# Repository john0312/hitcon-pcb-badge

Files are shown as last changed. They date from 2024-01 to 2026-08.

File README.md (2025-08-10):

# HITCON PCB Badge

## Firmware Development

execute `fw/merge.py` to merge STM32CubeIDE generated `main.c` with user code in `main.cc` into `main.cc`.

### Choose your hardware

In STM32CubeIDE, go to **Project > Build Configurations > Set Active > V1.1 / V2.0 / V2.1** to switch between hardware versions.  
Then go to **Run > Run Configurations** choose the correct Run Configuration
There are different firmware versions for each hardware revision.  
To identify your hardware version, check the back of your badge.
- V1.1 (2024 CMT Attendee)
- V2.0 (2025 first prototype)
- V2.1 (2025 last prototype)
- V2.2 (2025 Attendee)

## Timers and DMA Channels

- [x] IR Tx: PWM Output from TIM3_CH3, Output PB0, DMA1 Ch2
  - Compare: 63/4 = 16
  - Mode: Circular Normal Peripheral to Memory

| | Peripheral | Memory |
| --- | --- | --- |
| Increment Address | X | V |
| Data Width | Half Word  | Half Word |

- [x] IR Rx: DMA Triggered through TIM2_CH3, Input PA0 read by DMA1 Ch1
  - Compare: 105
  - Mode: Circular Peripheral to Memory

| | Peripheral | Memory |
| --- | --- | --- |
| Increment Address | X | V |
| Data Width | Half Word  | Half Word |

- [x] Led Rows/Cols: DMA Triggered through TIM1_UP, Output PB6-9(Rows), Output PB1-2/10-15(Cols), written by DMA1 Ch5
  - Mode: Circular Memory to Peripheral

| | Peripheral | Memory |
| --- | --- | --- |
| Increment Address | X | V |
| Data Width | Word | Word |

- [x] Led Brightness control: PWM Output from TIM3_CH2
- [x] Buttons: Reads Input PA4-10, PA15 through TIM4_CH2, DMA1 Ch4
  - Compare: 5
  - Mode: Circular Peripheral to Memory

| | Peripheral | Memory |
| --- | --- | --- |
| Increment Address | X | V |
| Data Width | Half Word  | Half Word |

- [x] Cross-board communication TX: USART2 TX, DMA1 Ch7
- [x] Cross-board communication RX: USART2 RX, DMA1 Ch6

- [x] TIM4: Operates at 100Hz for Button
  - Prescaler: 12000-1
  - Counter Period: 10-1
- [x] TIM3: Operates at 38kHz for PWM out.
  - Prescaler: 5-1
  - Counter Period: 63-1
  - Master Mode Enable
- [x] TIM2:
  - Prescaler: 0
  - Counter Period: 4-1
  - Slave Mode: External Clock
  - Trigger Source: ITR2 (TIM3 Update Event)
  - Operates at 1/4 speed of TIM3, synchronization needed for IR pulse alignment and brightness adjustment.
  - Also operates at 1/4 bit time for capturing IR.
  - TIM2 = 38/4 kHz = 9.5kHz.
  - Bit time = 4/9.5kHz = 421us (each bit is 16 pulse).
- [x] TIM1:
  - Prescaler: 5-1
  - Counter Period: 1500-1
  - LED refreshes at 3200/16 = 200Hz.

## Format

To check format, please install `clang-format` first.

```sh
# under hitcon-pcb-badge
./lint.sh # check format
./lint.sh -i # auto format
```

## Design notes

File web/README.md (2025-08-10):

# pcb-badge-leaderboard

## Development server

To start a local development server, run:

```bash
ng serve
```

## Building

To build the project run:

```bash
ng build
```

This will compile your project and store the build artifacts in the `dist/` directory. By default, the production build optimizes your application for performance and speed.

## Running unit tests

To execute unit tests with the [Karma](https://karma-runner.github.io) test runner, use the following command:

```bash
ng test
```

## Running end-to-end tests

For end-to-end (e2e) testing, run:

```bash
ng e2e
```

Angular CLI does not come with an end-to-end testing framework by default. You can choose one that suits your needs.

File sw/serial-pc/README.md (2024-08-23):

# Serial-PC

To verify the score on PCB badge, connect badge to PC by serial and run the command:

```
cargo run -- --dump

# help
cargo run -- --help
```

To connect to a specific serial device, use `--dev` command line argument.

To install `cargo` and relevant rust tools, follow the [Rust website](https://www.rust-lang.org/tools/install).

## Hardware Setup

badge-serial

## client

If you run `cargo run` twice, the second instance will become client mode, and you can send data to the badge.

```
cargo run -- --send-game-data --col 0 --data-int 1

# help
cargo run -- --help
```

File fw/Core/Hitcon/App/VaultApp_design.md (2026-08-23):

# VaultApp — design, invariants, and intended exploit

Internal author notes for the Vault heap-exploitation challenge. This is kept
out of the source comments on purpose: reading the code and solving the
challenge are separate concerns, and the comments should not spoil the solve.

## Overview

Vault-themed heap-exploitation CTF app. The player's badge (client) remote-
controls the server badge over the xboard connector by forwarding every button
press; the server runs the whole game and drives its own display. All logic
ships in every badge so a player can reverse their own board, but the real flag
exists only in the server build.

## Roles & startup

- Single `VaultApp`; the role is chosen at runtime by the non-const global
  `g_vault_role` (default `Client`). The server build flips the initial value to
  `Server` (`BADGE_ROLE == 0x10` defines `VAULT_SERVER`). Both role code paths
  stay in every binary, so the app is fully reverse-engineerable.
- On xboard peer connect the server enters the vault and re-sends `VAULT_HELLO`
  periodically (a `PeriodicTask` enabled in `OnEntry`, disabled in `OnExit`); a
  client switches into the vault on any hello. The periodic resend recovers the
  case where the client missed the first hello and would otherwise sit on
  `connect_menu`; `OnHelloPacket` is idempotent (already in the vault → no-op).
  Two clients connecting (both `Client`) send no hello and stay on the normal
  `connect_menu` — zero interference.

## Memory model (private pool, lives only in VaultApp.cc)

- `kSlots = 8` fixed-size slots; `kSlotSize = NAME_LEN + 2 = 24`.
- `union Slot { Profile; Key; Locked; Plain; }` — every member begins with a
  1-byte `id` at offset 0, so the "id" byte overlaps across all interpretations.
  - `Profile { u8 id; char name[23]; }` — `name` occupies offsets 1..23. `id` is
    a fixed header (see invariant 3).
  - `Key { u8 id; char desc[22]; u8 used; }` — `id` = the `Locked` id this key
    opens; `used` is the **last** slot byte (offset 23).
  - `Locked { u8 id; char content[23]; }` — the (fake/real) flag.
  - `Plain  { u8 id; char content[23]; }` — decrypted copy shown to the player.
- Allocator: LIFO free-list `free_stack_`; `Alloc` pops, `Free` pushes. This
  metadata is stored separately from `pool_`, so a leak that reads slot bytes
  never trips over allocator bookkeeping.
- The app-side object type is carried on `Ref { Type; Slot* }`, never stored in
  the slot. A leak therefore reads pure object bytes, and a `Ref` can end up
  describing a slot as a type it no longer holds.

## Load-bearing invariants — do NOT "clean these up", they ARE the challenge

1. `Free()` never scrubs the slot bytes and no code re-validates a pointer's
   liveness. Freed data lingers and dangling pointers stay usable → UAF.
2. `Discard()` frees the slot but intentionally does **not** touch `pinned_`.
   If the pin referenced that slot it now dangles. This single dangling-pin
   lifetime bug is the entire vulnerability.
3. `OnNamePacket` sets `profile.id = 0xFF`, outside the item id range
   `0..kNumItems-1`. A stale key that reinterprets a `Profile` slot then reads a
   non-item id, matches no `Locked`, and `Use()` performs only its stray write —
   it never enters the unlock branch. Because `name` starts at offset 1, the
   uploaded text cannot alias `id`, so the player cannot steer which item a stale
   key would unlock. Dropping this or using an item id reintroduces an
   unintended solve (and, worse, the unlock branch would free the profile slot
   and clear the pin, corrupting pool state).
4. `Key.used` is the last slot byte (offset 23). A full 22-char uploaded name
   lands its NUL terminator on that same byte, so the stray write `used = 1`
   overwrites the NUL and the printed name over-reads into the next slot.
5. `ResetGame` reverse-fills the free-list so the three `Locked`s seed into
   `pool[0]`, `pool[1]`, `pool[2]` as id 0, 1, 2. The id-2 `Locked` (the real
   flag) is therefore adjacent to the slot the exploit reuses (pool[1]), which
   is what the over-read lands in.
6. In the legitimate unlock path, `Use()` frees the matched `Locked` **last** so
   that slot tops the free-list and is the next `Alloc()` — this is what makes
   the "unlock frees a slot, next buy/upload reuses it" chain deterministic.
7. Keys are single-purchase (`bought_[]`); the id-2 key costs 999.

## Intended exploit (runs on the server, driven by forwarded buttons)

Start: money 100; key prices `{30, 30, 999}`. The id-2 `Locked` @ pool[2] holds
the real flag; its key costs 999 (unaffordable).

1. **Store → Buy key(id1)** (30): allocates a `Key{id 1}` into inventory.
2. **Inventory → Use key(id1)**: unlocks the id-1 `Locked` @ pool[1]. This
   allocates a new `Plain` slot, copies the decrypted id-1 content into it, and
   adds it to inventory; then it frees the key's slot and the id-1 `Locked`.
   The `Locked` is freed **last**, so pool[1] ends up on top of the free-list.
3. **Store → Buy key(id0)** (30): the allocation reuses pool[1] as a `Key{id 0}`.
4. **Inventory → Pin key(id0)**: sets `pinned_ = {Key, pool[1]}`.
5. **Inventory → Discard key(id0)**: frees pool[1] and removes it from
   inventory; `pinned_` is left untouched, so it now dangles at pool[1].
6. **Main → Name Upload** with a **22-char** name: the allocation reuses pool[1]
   as a `Profile` (`id = 0xFF`, `name` fills offsets 1..22, NUL at offset 23).
7. **Main → Pinned → Use**: the type check passes (the `Ref` still records
   `Key`); `k->used = 1` writes offset 23, clobbering the name's NUL; `t =
   profile.id = 0xFF` matches no `Locked`, so nothing is unlocked — only the
   write happens.
8. **Main → Print**: `view_str_ = profile.name` (offset 1). With the NUL at
   offset 23 gone, `strlen` runs past pool[1] into pool[2] = `Locked{id 2, real
   flag}`. The display pages show: `<22 name chars>` + `0x01` (used) + `0x02`
   (id 2) + the real flag, stopping at the flag's NUL.

Why each piece is needed:

- The **pin** is mandatory: after discard the key is only reachable through
  `pinned_`, so the stale `Use` can only come from the Pinned shortcut.
- The two non-zero bytes between the name and the flag (`used`, then the id) keep
  `strlen` from stopping early.
- Pool contiguity (stride `kSlotSize = 24`) makes the over-read land exactly on
  the adjacent item slot.

## Why it can't be shortcut

- The id-2 key costs 999 → the id-2 `Locked` can't be unlocked legitimately.
- `profile.id = 0xFF` + `name` at offset 1 → the uploaded text can neither alias
  the id nor steer a stale key to unlock an item.
- `Use()`'s unlock branch fires at most once per key: the `used` guard blocks
  re-entry, and on firing the key is removed from inventory + freed and the pin
  is cleared, so there is no live handle to invoke it again.

## Build / deploy

- **Server**: build the station badge with `BADGE_ROLE 0x10` (defines
  `VAULT_SERVER`); fill the real `kFlag0/1/2` in that branch (len
  `<= kSlotSize - 2`). Flash that one badge.
- **Everything else** ships as `Client` with dummy flags, so reversing a
  player's own badge reveals no real challenge content.

## xboard protocol

- Recv ids added before `MAX` in `Logic/XBoardRecvFn.h`: `VAULT_HELLO_ID`,
  `VAULT_BTN_FWD_ID`, `VAULT_NAME_REQ_ID`, `VAULT_NAME_RESP_ID`.
- Packets (`VaultCommon.h`): `VaultBtnPacket { u16 button; }`,
  `VaultNamePacket { char name[kVaultNameBufLen]; }` (`kVaultNameBufLen =
  NAME_LEN + 1 = 23`). Hello and name-req carry a single ignored marker byte.
- The wire buffer size (`kVaultNameBufLen`) is deliberately independent of the
  pool slot size (`kSlotSize`).

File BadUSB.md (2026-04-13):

# BadUSB

(in hex)

```python
device.write(arr)
```

The first byte of `arr` is the Report ID (value 2).  
If `len(arr) > 9`, every 10th, 20th, etc., byte is also a Report ID (2) and will be ignored.  
This means that for the first nine elements of `arr`, there are eight data bytes. Starting from the 10th byte, each segment consists of one Report ID followed by nine data bytes.
**The simplest approach is to always use an array of size 9, as the firmware is designed to handle this format.**
These results were tested on macOS; behavior on Linux may differ slightly but is generally the same.

- 01 XX XX XX XX XX… Set Name
- 02 Clear BadUSB Script
- 03 XX XX Start writing script + script length + CRC32 + ...

  - FF XX delay(20ms per unit)
  - FE XX Modifier
  - FD finish script
  - other: keycode
- 04 XX XX XX XX YY YY YY YY ZZ
  - XX write address
  - YY content
  - ZZ type, bytes, half word, or word

- 05 XX XX XX XX ZZ
  - XX read address
  - ZZ type, bytes, half word, or word

USB return

FF action done

[USB HID Keyboard scan codes](https://gist.github.com/MightyPork/6da26e382a7ad91b5496ee55fdc73db2)

## Windows 開發紀錄

BadUSB 的攻擊腳本是透過 HID 寫入 badge，在 mac 和 linux 上都可以寫入 hidraw，但 windows 上無法寫入。根據搜尋到的資料推測是 windows 不接受對一般鍵盤的 hid 界面寫入任意格式的資料，而 badge 已經模擬成鍵盤因此無法寫入。解決辦法是新增獨立的 usb interface，其中一個是鍵盤，另一個是自訂 hid，這樣 windows 就不會阻止對自訂 hid 的寫入操作了。

USB 裝置描述大致如下

Device Descriptor -> Configuration Descriptor -> Report Descriptor

### Device descriptor

宣告 vendor id (VID), product id (PID)

### Configuration Descriptor

這裡其實包含很多種 descriptor

- Configuration Descriptor * 1
  - Interface Descriptor * n
    - Class-Specific Descriptor: 根據 bInterfaceClass 緊接在後
    - Endpoint Descriptor * m

就是在這裡增加 interface 數量。修改時須參考 USB HID spec

### Report Descriptor

- Collection
  - Report * n

一個 interface 對應到一個 report descriptor，每個 report descriptor 中可能包含多個功能相近的 report，input (to PC) 和 output (from PC) 也是分開的 report。以鍵盤為例，input 是按鍵觸發事件，output 可以是 caps lock 亮燈。

### Debug 工具

```sh
sudo dmesg -w
```

顯示目前插入的 usb 裝置狀況

```sh
hexdump -C /sys/bus/usb/devices/3-1/3-1:1.0/0003:0483:5750.0007/report_descriptor
```

顯示 report descriptor，可丟 copilot 分析

```sh
sudo lsusb -v -d 0483:5750
```

顯示經過解析的 device descriptor, configuration descriptor 等

wireshark: 可以抓 usb 溝通過程

### References

- [使用STM32 H7实现HID组合设备（键盘、鼠标） - 来自Madliar](https://www.madliar.com/notebook/publish/i/caoliang.net/2023-08-27/-shi-yong-STM32H7-shi-xian-HID-zu-he-she-bei--jian-pan--shu-biao-.html)
- [Device Class Definition for Human Interface Devices (HID) version 1.11.pdf](https://www.usb.org/sites/default/files/documents/hid1_11.pdf)
- [Defined Class Codes | USB-IF](https://www.usb.org/defined-class-codes)
- [CaptureSetup/USB - Wireshark Wiki](https://wiki.wireshark.org/CaptureSetup/USB)
- [USB Component: Interface Descriptor](https://www.keil.com/pack/doc/mw/usb/html/_u_s_b__interface__descriptor.html)
- [【经验分享】基于STM32使用HAL库实现USB组合设备之多路CDC - STM32团队 ST意法半导体中文论坛](https://shequ.stmicroelectronics.cn/thread-634270-1-1.html)

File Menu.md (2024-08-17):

```mermaid
flowchart TD
    A[Entry Point] --> B(ShowNameApp)
    B -----> |"Mode\n(single player)"| main_menu_app(MainMenuApp)

    subgraph single_player
        main_menu_app --> D(BadUSB)
        main_menu_app --> E(Snake)
        main_menu_app --> F(Dino)
        main_menu_app --> G(Tetris)
    end

    D --> main_menu_app
    E --> show_score_app
    F --> show_score_app
    G --> show_score_app
    show_score_app(ShowScoreApp) --> |"Button\n(single player)"| main_menu_app

    B -----> |"Mode\n(two player)"| connect_menu_app(ConnectMenuApp)
    subgraph two_player
        connect_menu_app --> O(Tetris)
        connect_menu_app --> P(Snake)
        connect_menu_app --> Q(xchg)
    end

    O --> show_score_app
    P --> show_score_app
    Q --> show_score_app
    show_score_app --> |"Button\n(two player)"| connect_menu_app

    B ------> |Mode Long Pulse| H(NameSettingApp)
    subgraph settings
        H --> I(EditNameApp)
        H --> J(NameDisplayApp)
        J --> K(Name + Score)
        J --> L(Name Only)
        J --> M(Score Only)
    end
```

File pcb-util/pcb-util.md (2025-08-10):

# pcb-util

pcb-util provides an utility tool for flashing FW to PCBs more effiecient in production.

# CLI Tool User Instruction
## Preparation
### Install STM32ProgrammerCLI.exe
1. Log in to MyST on STM32 website
2. Download STM32CubeProgrammer from the [link](https://www.st.com/en/development-tools/stm32cubeprog.html)
3. Unzip the en.stm32cubeprg-win32-v2-17-0.zip
4. Install the SW by double-click SetupSTM32CubeProgrammer_win32 with default configuration
5. Copy the path to STM32_Programmer_CLI. It should be something like this:
  ```
  C:\Program Files (x86)\STMicroelectronics\STM32Cube\STM32CubeProgrammer\bin\STM32_Programmer_CLI.exe
  ```

### Prepare files to flash
1. Download pcb-util_CLI.zip from Github repo.
2. Extract the folder

Here are the files that should be in pcb-util to start flashing with CLI tool

.\pcb-util_CLI
1. fw.elf
2. config.ini
3. pcb-util_CLI.exe

### Set Path to STM32ProgrammerCLI.exe
1. Put the path to ```fw.elf``` into ```[Path] FW_ELF_PATH``` in  ```config.ini``` 
2. Put the path into ```[Path] ST_PPROGRAMMER_PATH``` in  ```config.ini``` 

### Check pcb-log Server
Please check the pcb-log server is ready.

If not, disable this function by changing ```EN_PCB_LOG = 1``` in ```config.ini```

## Use pcb-util_CLI tool
1. Run:
    ```
    python pcb-util_CLI.py
    ```
2. The CLI tool will automatically detect the pcb-badge connected and flash the fwMOD.elf. Remove the pcb-badge once upload was finished
3. If you add/remove ST-Link connected to the PC, press r'to refresh the list of ST-Link 
4. press 'q' to quit the CLI tool

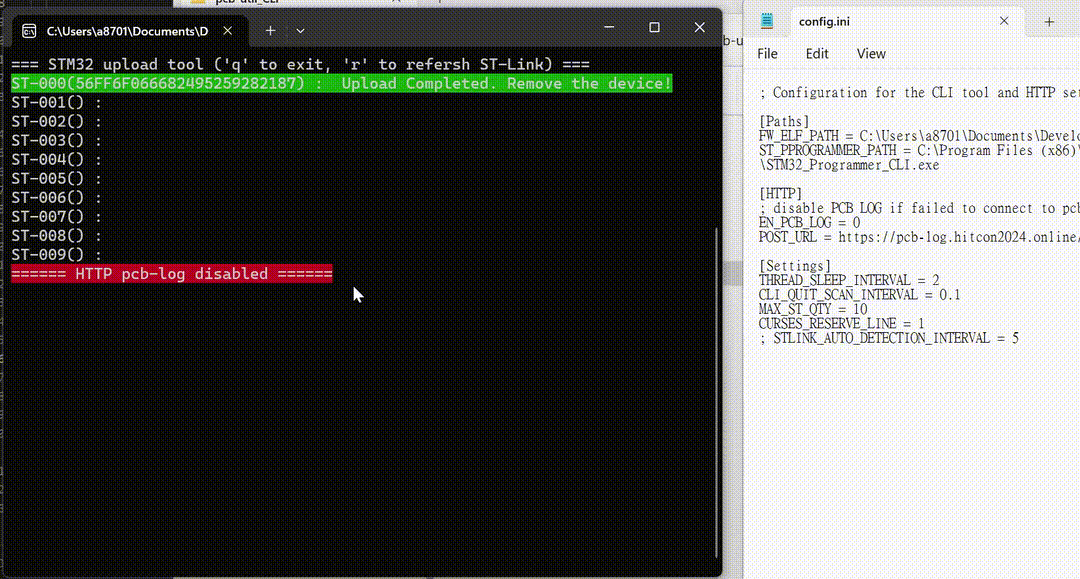
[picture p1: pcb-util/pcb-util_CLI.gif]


---
---

# For Development or Custom use

## Dev env
- Python ver
  * python 3.12
### Packages ver
- UI
  - [Streamlit](https://streamlit.io/)
      - 1.37.0
- Upload Process
  - STM32_Programmer_CLI
    -  2.17.0
-  TODO: EXE generation
   - pyinstaller
     - 24.2

## Application
The pcb-util consist of several utility scripts describing as follows
- **ReplaceELF.py (Done)**
  1. Duplicate the compiled ELF as fwMOD.elf to be modified
  2. Find & Replace the two uint8 arrays in fwMOD.elf with specific array for individual pcb-badge
  3. Printe the array around in organized HEX to verify ELF modification
- **fw_flash.py (Done)**
  - Class definition for automating the interaction with STM32_Programmer_CLI & ST-Link
- **cli_example.py (Done)**
  - An example of a multi-thread CLI app that handles each ST-Link
  - Try it out [here](#cli-tool-user-instruction)
  - Some knwown bug can be fix with some notes [here](#faq-of-cli_example)
- **pcb-util_CLI (Done)**
  - Integrate cli_examply.py and ReplaceELF.py
  - TODO: Test logging PerBoardSecret to Server
- **setting.py**
  - Some configurations for pcb-util
- **ui.py**
  - A streamlit app which spawns a web server
  - Check out [here](#try-out-ui) if your want to try it out
- **ui_example.py (Debugging)**
  - A streamlit app of a multi-thread CLI app that handles each ST-Link
  - TODO: display connected ST-link
  - TODO: auto-detect ST-Link

## Try out UI
[Streamlit](https://streamlit.io/)
to try it out:
1. Set up your Python development environment.
2. Run:
    ```
    pip install streamlit
    ```
3. Validate the installation by running official Hello app:
    ```
    streamlit hello
    ```
4. Point to directory of \hitcon-pcb-badge\pcb-util and run the UI app for HITCON
    ```
    streamlit ui.py
    ```

## FAQ of cli_example
* curses 出錯 : 

  * 因留給他的空間不夠，顯示空間拉大就好
* spyder 終端機跳掉
  * 用 vscode 執行
  
## Some notes

### ref links

* [STM32_Programmer_CLI.exe基本命令介绍](https://blog.csdn.net/yxy244/article/details/108453398)

### issue list

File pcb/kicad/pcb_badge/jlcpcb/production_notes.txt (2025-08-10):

Adjusted fields:
- Qty: Adjust as appropriate
- PCB Color: Black
- Surface Finish: LeadFree HASL
- Confirm Production File: Yes for Production Run
- Electrical Test: Flying Probe Fully Test
- Mark on PCB: Remove Mark
- PCB Assembly: On
- PCBA Type: Standard
- Assembly Side: Both Sides
- Confirm Parts Placement: Yes for Production Run

Known missing parts:
The following message will be shown: "The below parts won't be assembled due to data missing.
C34,J2,J3,D1,J7,R30,D3,D167,D166,R22,D165,R36,D164,R35,D163,D162,R29,D160 designators don't exist in the CPL file."

Remember to check/select J1.

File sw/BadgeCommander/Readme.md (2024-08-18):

## 1. 創建一個 Udev 規則：

    創建或編輯一個 Udev 規則文件，例如 /etc/udev/rules.d/99-hid.rules。
    添加類似以下內容的規則：

bash

SUBSYSTEM=="hidraw", KERNEL=="hidraw*", MODE="0666"

2. 重新加載 Udev 規則：

    保存文件後，重新加載 Udev 規則：

bash

sudo udevadm control --reload-rules
sudo udevadm trigger

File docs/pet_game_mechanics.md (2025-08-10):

# 設備條件
畫面 8x16 
LED燈藍色和紅色，一台只有一種顏色

# 遊戲機制

- 第一次進入遊戲，可以選擇要孵狗蛋還是貓蛋
- 選擇後開始計搖晃次數，顯示孵蛋進度條（計次400下後孵蛋成功）
    - Global 晃動次數。
- 若孵蛋成功，再次進入遊戲畫面時即可看到你的寵物
    - Optional: 孵蛋成功小動畫（Justin 要畫嗎)
        > Yee (ok)
- 寵物有「生命值」、「等級」、「飽食度」三個數值
    - 生命值：三顆心，生命值歸零寵物進入虛弱狀態
        - aka, 能輸幾次
    - 飽食度：全滿為4，每1小時扣1飽食度，若飽食度歸零寵物進入虛弱畫面（不顯示，隱藏數值）
    - 等級：初始為1等，滿等999等
        - 步數升級公式 (可2選1)
    
  1. (如果很麻煩可以簡單暴力) 500步升1等
  2. 自創一個步數公式，Gemini建議 https://gemini.google.com/share/4625026bbfe0
  >  我們採用「總經驗值制」，每一步都算作 1 點經驗值 (XP)。升級所需的總經驗值遵循非線性成長。
  >  升到下一級 (L+1) 所需的步數（經驗值）公式為：
  > StepsForNextLevel(L)=TotalStepsForLevel(L+1)−TotalStepsForLevel(L)
其中，升到等級 L 所需的總步數公式為：
TotalStepsForLevel(L)=80×(L−1) 
1.5
 +100(當 L>1)
80：基礎係數，可調整整體難度。
1.5：指數，決定了曲線的陡峭程度，1.5 可確保中後期成長顯著變慢。
100：初始步數，讓升到 Lv.2 只需要 100 步，給予玩家立即的成就感。

-  可做行動
    - 訓練：進度條 QTE，若5次全中增加1等
        - 若成功3次增加1等，成功5次增加10 等
    - 餵食：可愛動畫，增加一格飽實度，畫面顯示你是一個好駭客
    - 戰鬥
        - 雙方進入戰鬥畫面，對接後顯示「Are you ready?」 任何一方按確認後進入戰鬥畫面
            > too many words, changed to icon - Yee (ok)
        - 戰鬥方式：NBA shot meter (Aoaa 看得懂)
            - 對戰方式：
                - Hitbox 每次隨機出現，下方指示物會來回走一次，玩家需要在下方指示物對準Hitbox時按下確認鍵，才算成功。
                - 指示物來回走一次以後會改變hitbox位子
                - 此過程進行5次後計分
            - 對戰後計算
                - John 負責算函數，或可參考 https://gemini.google.com/share/4625026bbfe0
                >為了實現「技術 > 等級」，我們設計一個「戰力指數 (Power Score)」，指數高者獲勝。
PowerScore=(成功次數×SkillWeight) 
2
 +(等級×LevelWeight)
考量到 PCB Badge 的運算能力，我們可以使用簡化且有效的整數運算：
PowerScore=(成功次數) 
3
 ×10+等級
成功次數 (S)：範圍 0-5。使用 三次方 可極大化技術的影響力。
10：技術權重係數，確保 S 的增長效益遠超等級。
等級 (L)：範圍 1-999。作為次要的決勝因素。

                - 兩個數字比大小，贏者勝 
                    - 一局比大小結束
                - 若成功次數為4次，有50%機率引發爆擊
                - 若成功次數為5次，有100%機率引發爆擊，直接讓對方進入虛弱狀態
                - 贏的一方提升3等
- 小駭客中心(寶可夢中心)：Badge與寶可夢中心對接，補滿三顆心和飽食度
- 若寵物進入虛弱狀態，降一等，並無法進行任何活動，需要到寶可夢中心回滿血後才可繼續遊戲

# 遊戲功能階層

(孵蛋前)
- 小駭客
    - 畫面顯示選擇狗狗 OR 貓貓，選擇後進入孵蛋進度條

(孵蛋後)
- 小駭客
    - 寵物畫面（希望可以是動畫）
        - 狀態顯示
            - 血條
            - 等級/等級條
            - 飽實度
        - 訓練
        - 餵食
        - 戰鬥

# 畫面需求 for Justin
1. 蛋
2. 孵蛋成功小動畫
3. 狗&貓 (8x16的版面都可以用，希望可以動)
4. 貓虛弱畫面/狗虛弱畫面
5. 寶可夢中心 (愛心跑馬燈之類的)

---

### 跨版對戰相關

> 註：畫面不用額外刻

1. tama APP pet idle 狀態下，偵測板子是否對插 
    * 參考畫面 截圖 2025-07-06 下午6.23.48
2. 確認對插，跳出戰鬥確認頁面 
    * 截圖 2025-07-06 下午6.24.52

3. 雙方確認戰鬥，==交換寵物種類==。(按退出則回 tama app pet idle) 
4. 進入戰鬥對峙互看頁面
    * 截圖 2025-07-06 下午6.25.25
5. 畫面 delay 幾秒後跳出 "Battle start" page
6. "Battle start" page 過幾秒內進入 QTE game page
7. 進行五次 QTE，統計成功次數(需計時 timeout)
8. 完成QTE的，等待

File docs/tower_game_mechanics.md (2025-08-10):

# 設備數量
15-20個基地台
基地台和Badge可雙向溝通
基地台可傳輸距離約5-10公尺

# 遊戲機制

## 遊戲機制簡介
1. 一開始所有都是中立塔台，中立塔台需要分數達到一定程度才會被佔領
    - 塔台數值：設定分數下限 & 上限，中間有一區間會判定為中立塔台。EX: -1000 ~ 1000, 中間-300~300為中立值
3. 會眾透過遊戲、互動取得分數，分數會立即被使用到攻擊／防禦附近的塔台
4. 塔台數值會隨時間下降，因此已經被佔領的塔台，若有一段時間都沒有人去加減分數，會回到中立塔台
5. 佔領塔數較多的該隊獲勝

待確認：
1. 有鑽漏洞（讓會眾玩Hacking）的機制嗎
2. 可以當內鬼?

## 分數類別 & 分數使用機制

### 分數類別
~~- 可使用分數：玩任一遊戲，還可以支配的分數~~
- 已使用分數

### 分數使用機制

#### 獲得當下立刻使用
* 人潮明顯，好拍照，但會怕把議程空間擠爆
* 不需要額外有一個數值儲存已取得的分數

## 取得分數的方法
注意：這邊所有的分數定義都是先以會眾角度為考量，因此先不考慮藍隊實際上是+10/ 紅隊實際上計分是-10這個問題
* 站在塔台旁邊搖晃Badge
    * 一般塔台
        *  10秒內搖晃次數超過20次 +10分
            * 設定原因：希望是有意識的搖晃再計分，不要單純走路就計分
        * 每5秒多+1分
        * EX 連續搖晃20秒時，會變成10+11分。搖晃30秒時，會變成10+11+12。搖晃越久分數增加越多
    * 贊助商塔台
        * 10秒內搖晃次數超過20次 +20分
        * 每5秒多+2分
        * EX 連續搖晃20秒時，會變成20+21分。
* 小遊戲：
    * Dino
        * 每5秒計2分
        * 每5秒多+1分
        * EX: 成功跑15秒，分數為2+3+4
    * Snake
        + Snake score 每5分計1分
        + 每5分多+1分
        + 單機模式，EX: 若Snake score結果顯示為35，分數為= 1+2+3+4+5+6+7
        + 對戰模式：勝利的一方獲得2倍的分數，輸的一方獲得一倍的分數
        (給石頭：分數後端算。勝利與否只看分數高低。即便貪食蛇有人先撞牆，還是分數高的贏。若平分的話就是送一樣的分數)
    * Tetris
        * Tetris Score 每15分計1分
        * 每15分多+1分
        * 單機模式，EX: 若Tetris score結果顯示為150，1+2+3+4+5+6+7+8+9+10
        * 對戰模式：勝利的一方獲得2倍的分數，輸的一方獲得一倍的分數
        (給石頭：分數後端算。勝利與否只看分數高低。即便貪食蛇有人先撞牆輸了。若平分的話就是送一樣的分數)
* 贊助商活動
    * 共有 13 個贊助商攤位
    * 跟任一贊助商攤位對接，可獲得200分。若跟所有贊助商都對接過一次，隨即攻擊/防禦附近的塔台1200分

* ReCTF：解題可以獲得分數倍率
    * 預設題目有24題
    * CTFd 登入 官網 SSO Token 後，可以在 Profile 頁面綁定 Badge。(活動前edward會事先提供一個解多少題的清單)
    * 每解一題可以增加0.04的分數倍率，EX: 倍率為1.04、1.08、1.12、1.16.....，全部解完的分數倍率為兩倍(先成上去後小數點四捨五入)

## 遊戲結算
* 團隊：佔領塔數較多的那隊獲勝（獎品待確認）
* 個人：已使用分數最高者獲勝

設定獲勝條件

## 記分板
* 個人已經輸出過的分數
* 地圖：各地佔領情況，分數差異

archieve
胎死腹中的想法
~~有沒有台主~~

分數儲存後使用 (建議)
說明：獲得分數後儲存起來，之後再決定要將分數加到哪個塔台
* 人流不會都擠在基地台旁邊（畢竟基地台可能會放在議程空間裡面）
* 在何時何地都可以參與遊戲，可以回家繼續玩小遊戲累積分數

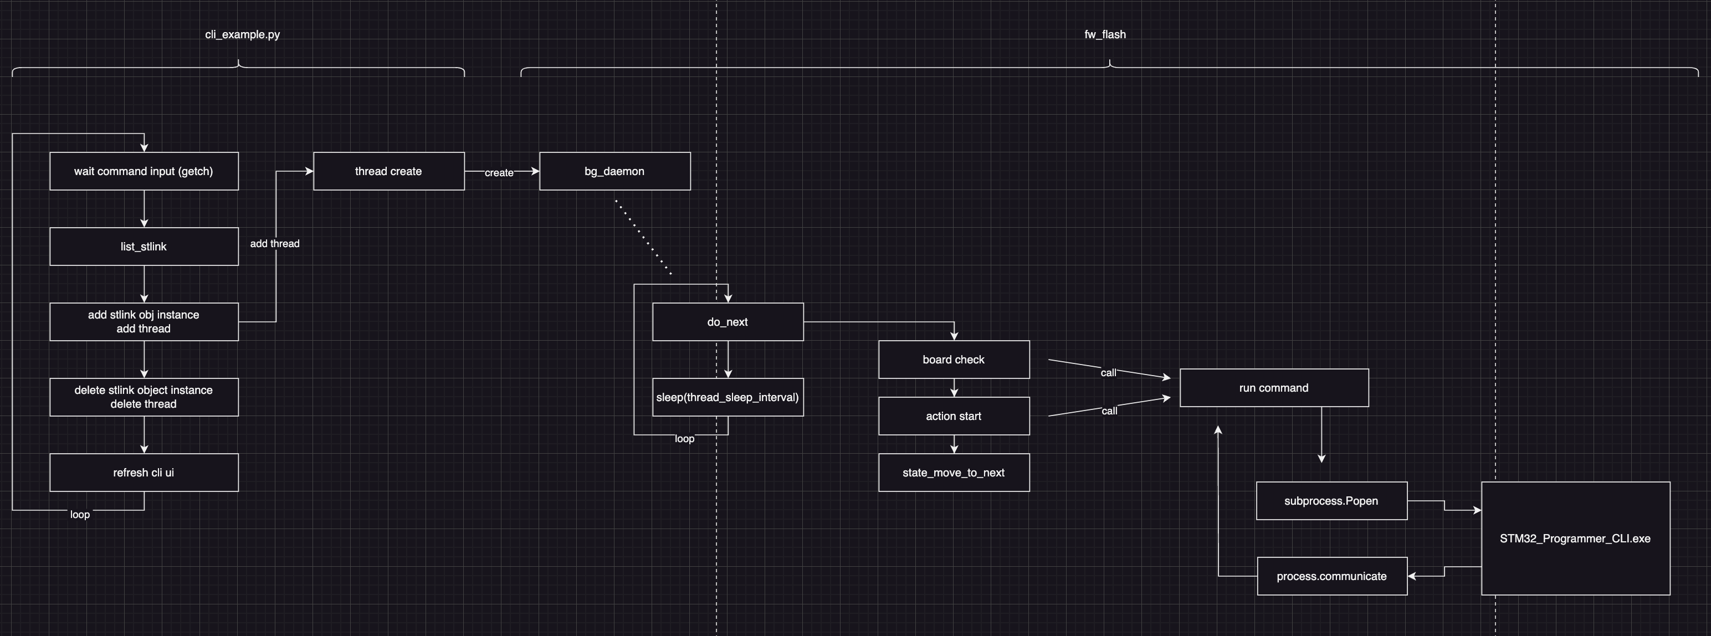
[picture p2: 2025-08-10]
pcb-util/reference/stm_cli_uploader.png

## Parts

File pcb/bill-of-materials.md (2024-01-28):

Bill of Material
================

- STM32F108C8T6: LQFP48
  * 大廠要找代理商
- MicroUSB
  * 有很多小廠，要尋找並詢價還有取得Datasheet
- LED Matrix: 0603
- AMS1117: SOT223
- IRM3638: DIP3
- AAA Battery
  * 有很多小廠，要尋找並詢價還有取得Datasheet
- Crystal: 2016
- TLV703: SOT-23-5
  * 台灣有原廠跟代理商，但一捲是3000顆，看有沒有部份賣的。2.8V or 3.0V
- 2N7002: SOT-23

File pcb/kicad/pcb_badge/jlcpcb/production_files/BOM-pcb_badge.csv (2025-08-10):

Comment | Designator | Footprint | LCSC
0.1u | C1,C21,C30,C31,C32,C33,C40,C50,C51,C80 | C_0402_1005Metric_Pad0.74x0.62mm_HandSolder | C1525
1u | C10,C11 | C_0603_1608Metric_Pad1.08x0.95mm_HandSolder | C152900
20p | C37,C38 | C_0402_1005Metric_Pad0.74x0.62mm_HandSolder | C1554
4.7u | C60 | C_0603_1608Metric_Pad1.08x0.95mm_HandSolder | C1705
10M | R11,R4 | R_0402_1005Metric_Pad0.72x0.64mm_HandSolder | C177265
TLV70328DBVR | U1 | SOT-23-5 | C19631758
10u | C20,C22,C23,C24,C25,C26,C92 | C_0603_1608Metric_Pad1.08x0.95mm_HandSolder | C19702
20R | R1,R2 | R_0402_1005Metric_Pad0.72x0.64mm_HandSolder | C203133
QX2304L33F | U2 | SOT-23-5 | C219039
100 | R61 | R_0402_1005Metric_Pad0.72x0.64mm_HandSolder | C25076
220 | R14 | R_0402_1005Metric_Pad0.72x0.64mm_HandSolder | C25091
300 | R90,R91,R92,R93,R94,R95,R96,R97 | R_0402_1005Metric_Pad0.72x0.64mm_HandSolder | C25102
470 | R21,R31,R32,R33,R34,R8,R9 | R_0402_1005Metric_Pad0.72x0.64mm_HandSolder | C25117
SW_MEC_5E | SW1,SW2,SW3,SW4,SW5,SW6,SW7,SW8 | SOIC4_TL3301SPF160RGTAPE_EWI | C255812
100k | R16,R17,R18,R19,R5,R6,R7 | R_0402_1005Metric_Pad0.72x0.64mm_HandSolder | C25741
4.7k | R20,R3,R50,R51 | R_0402_1005Metric_Pad0.72x0.64mm_HandSolder | C25900
5.1k | R24,R25 | R_0402_1005Metric_Pad0.72x0.64mm_HandSolder | C25905
CYL104R-33UH | L20 | L_10.4x10.4_H4.8 | C2879699
Conn_01x03_Pin | J5 | PinHeader_1x03_P2.54mm_Vertical | C2897385
DEALON USB-TYPE-C-018 | J1 | DEALON USB-TYPE-C-018 | C2927038
110R | R164 | R_1206_3216Metric_Pad1.30x1.75mm_HandSolder | C2934192
SOD4007-MS | D18,D2 | D_SOD-123F | C3008061
TAXM8M4RFDCET2T | Y1 | Oscillator_SMD_Abracon_ASE-4Pin_3.2x2.5mm | C403948
SI2302 | Q1 | SOT-23 | C4748714
2N7002 | Q9,Q90,Q91,Q910,Q911,Q912,Q913,Q914,Q915,Q92,Q93,Q94,Q95,Q96,Q97,Q98,Q99 | SOT-23 | C4748728
NSR0320MW2T1G | D9 | D_SOD-323_HandSoldering | C48192
Conn_01x03_Pin | J4 | PinHeader_1x03_P2.54mm_Vertical | C5383096
0 | R10,R23 | R_0402_1005Metric_Pad0.72x0.64mm_HandSolder | C60485
NEWOPTO XYC-IRA2835A90-X4 | D161 | LED_PLCC_2835_Handsoldering | C6081290
74HC238 | U4,U8 | SOP-16_3.9x9.9mm_P1.27mm | C7432189
STM32F103CBT6 | U3 | LQFP-48_7x7mm_P0.5mm | C8304
IRM-H638T/TR2 | U6 | IRM-H638T | C91447
JSM2301S | Q2 | SOT-23 | C916399
BAT_2 | BT1 | BH-AAA-B5AK001 | C964881
LED | D00,D01,D02,D03,D04,D05,D06,D07,D10,D100,D101,D102,D103,D104,D105,D106,D107,D11,D110,D111,D112,D113,D114,D115,D116,D117,D12,D120,D121,D122,D123,D124,D125,D126,D127,D13,D130,D131,D132,D133,D134,D135,D136,D137,D14,D140,D141,D142,D143,D144,D145,D146,D147,D15,D150,D151,D152,D153,D154,D155,D156,D157,D16,D17,D20,D21,D22,D23,D24,D25,D26,D27,D30,D31,D32,D33,D34,D35,D36,D37,D40,D41,D42,D43,D44,D45,D46,D47,D50,D51,D52,D53,D54,D55,D56,D57,D60,D61,D62,D63,D64,D65,D66,D67,D70,D71,D72,D73,D74,D75,D76,D77,D80,D81,D82,D83,D84,D85,D86,D87,D90,D91,D92,D93,D94,D95,D96,D97 | LED_0402_1005Metric_Pad0.77x0.64mm_HandSolder | C965790
LSM6DS3TR-C | U5 | QFN_S3TR-C_STM | C967633
NC | D160 | LED_PLCC_2835_Handsoldering
Conn_01x02_Pin | J7 | PinHeader_1x02_P2.54mm_Vertical
NC | D3 | LED_0603_1608Metric_Pad1.05x0.95mm_HandSolder
Conn_01x04_Pin | J3 | PinHeader_1x04_P2.54mm_Vertical
NC | R29 | R_0402_1005Metric_Pad0.72x0.64mm_HandSolder
NC | R36 | R_0402_1005Metric_Pad0.72x0.64mm_HandSolder
NC | R35 | R_0402_1005Metric_Pad0.72x0.64mm_HandSolder
NC | C34 | C_0402_1005Metric_Pad0.74x0.62mm_HandSolder
NC | R22 | R_0402_1005Metric_Pad0.72x0.64mm_HandSolder
NC | D1 | D_SOD-323_HandSoldering
NC | R30 | R_0402_1005Metric_Pad0.72x0.64mm_HandSolder
NC | D164 | LED_PLCC_2835_Handsoldering
NC | D166 | LED_PLCC_2835_Handsoldering
Conn_01x02_Pin | J2 | JWT_A3963_1x02_P3.96mm_Vertical
NC | D163 | LED_PLCC_2835_Handsoldering
NC | D167 | LED_PLCC_2835_Handsoldering
NC | D162 | LED_PLCC_2835_Handsoldering
NC | D165 | LED_PLCC_2835_Handsoldering
NC | R165 | R_1206_3216Metric_Pad1.30x1.75mm_HandSolder
NC | R166 | R_1206_3216Metric_Pad1.30x1.75mm_HandSolder
NC | R162 | R_1206_3216Metric_Pad1.30x1.75mm_HandSolder
NC | R167 | R_1206_3216Metric_Pad1.30x1.75mm_HandSolder
NC | R163 | R_1206_3216Metric_Pad1.30x1.75mm_HandSolder

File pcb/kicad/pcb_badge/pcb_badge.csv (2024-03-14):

Designator | Value | Footprint | Qty | Ref
C01 | 0.1u | 0603 | 1 | SMD陶瓷電容
C30,C31,C32,C33,C34,C40,C51 | 0.1u | 0402 | 7 | SMD陶瓷電容
C10,C11 | 1u | 0603 | 2 | SMD陶瓷電容
C20, C50 | 10u | 0603 | 2 | SMD陶瓷電容
C21 | 22u | 0603 | 1 | SMD陶瓷電容
C37,C38 | 20p | 0402 | 2 | SMD陶瓷電容
D00~D77 | LED | 0402 | 64 | 紅光或白光LED
D1, D2 | NSR0320MW2T1G | SOD-323 | 2 | 蕭特基二極體
D3 | IR LED 940nm | 0603 | 1
J1 | 10118192-0002LF |  | 1 | https://www.mouser.tw/ProductDetail/Amphenol-FCI/10118192-0002LF?qs=KVgMXE4aH4nIkuWlMxQzog%3D%3D
J2 | 2pin header | 2pin 2.54mm | 1 | https://reurl.cc/E40Aqn
J3 | 4pin header | 4pin 2.54mm | 1 | https://reurl.cc/Z9kmRg
Q1,Q2,Q3,Q4,Q5,Q6,Q7,Q8 | 2N7002 | SOT-23 | 8 | NMOS FET
R1,R2 | 20R | 0402 | 2
R3 | 4.7k | 0402 | 1
R4 | 47k | 0402 | 1
R5,R10,R20,R21,R22,R40,R41,R42,R43,R44,R45,R46,R47,R48,R49,R410 | 0 | 0402 | 16
R30 | 1k | 0402 | 1
R50 | 47 | 0402 | 1
R80-R87 | 300 | 0402 | 8
SW1-SW8 | Tactile Switch | TS04 | 8 | https://reurl.cc/4jzKQL
U1 | TLV70328 | SOT-23-5 | 1
U2 | AMS1117 | SOT-223-2 | 1
U3 | STM32F103C8 | LQFP48 | 1
U4 | CD74HCT238M | SOIC-16(SOP-16) | 1
U5 | IRM-3638T |  | 1
Y1 | 8MHz | Oscillator:Oscillator_SMD_Abracon_ASE-4Pin_3.2x2.5mm | 1 | 石英震盪器
Y2 | 32.768kHz | Crystal:Crystal_SMD_3215-2Pin_3.2x1.5mm | 1 | 石英震盪器

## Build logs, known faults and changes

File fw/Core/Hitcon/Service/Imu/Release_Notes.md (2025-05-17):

---
pagetitle: Release Notes for LSM6DS3TR-C Component
lang: en
header-includes: <link rel="icon" type="image/x-icon" href="_htmresc/favicon.png" />
---

::: {.row}
::: {.col-sm-12 .col-lg-4}

<center>
# Release Notes for LSM6DS3TR-C Component Driver
Copyright &copy; 2021 STMicroelectronics\

ST logo (https://www.st.com)
{.logo}
</center>

# License

This software component is licensed by ST under BSD 3-Clause license, the "License".
You may not use this component except in compliance with the License. You may obtain a copy of the License at:

[BSD 3-Clause license](https://opensource.org/licenses/BSD-3-Clause)

# Purpose

This directory contains the LSM6DS3TR-C component drivers.
:::

::: {.col-sm-12 .col-lg-8}
# Update history

::: {.collapse}
<input type="checkbox" id="collapse-section1" aria-hidden="true">
<label for="collapse-section1" aria-hidden="true">V1.0.0 / 18-June-2021</label>
<div>

## Main changes

### First release

- First official release [ref. DS v3.0]

##

</div>

<input type="checkbox" id="collapse-section2" aria-hidden="true">
<label for="collapse-section2" aria-hidden="true">V1.1.0 / 01-June-2023</label>
<div>

## Main changes

- Add __weak directive to read/write registers routines
- Extend stmdev_ctx_t structure with mdelay callback
- repo name changed adding '-pid' extension

##

</div>

<input type="checkbox" id="collapse-section3" aria-hidden="true">
<label for="collapse-section3" aria-hidden="true">V2.0.0 / 20-Mar-2024</label>
<div>

## Main changes

- Fixed code style (Artistic Style Version 3.4.13)
- Add "const" to ctx arg for all APIs

##

</div>

<input type="checkbox" id="collapse-section4" checked aria-hidden="true">
<label for="collapse-section4" aria-hidden="true">V2.0.1 / 20-Jun-2024</label>
<div>

## Main changes

- updated README.md file with tag reference and mdelay description

##

</div>
:::

:::
:::

<footer class="sticky">
::: {.columns}
::: {.column width="95%"}
For complete documentation on LSM6DS3TR-C,
visit:
[LSM6DS3TR-C](https://www.st.com/content/st_com/en/products/mems-and-sensors/inemo-inertial-modules/lsm6ds3tr-c.html)
:::
::: {.column width="5%"}
<abbr title="Based on template cx566953 version 2.0">Info</abbr>
:::
:::
</footer>

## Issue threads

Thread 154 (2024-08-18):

Lance is too strooooooong

Alx-Lai, 2024-08-18:

ktpss95112, 2024-08-18:
I'm willing to give out my heart and liver.

chuanchan1116, 2024-08-18:
<(_ _)>

lisasasasa, 2024-08-18:
So Coooooooooooooooooooool

justinlin099, 2024-08-19:
Lua

Alex Lai ***@***.***> 於 2024年8月18日 週日 下午5:34 寫道：

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

doraeric, 2024-08-19:
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

ktpss95112, 2024-08-23:
Lance is tuuuuuzki
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

Closed 2024-08-18.

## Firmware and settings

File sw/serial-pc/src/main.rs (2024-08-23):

use clap::Parser;
use crc::Crc;
use parser::{PacketParser, PING_TYPE};
use rayon::prelude::*;
use sha3::{Digest, Sha3_256};
use std::{
    cmp::Ordering,
    io::{self, Read, Write},
    net::{TcpListener, TcpStream},
    thread,
    time::Duration,
};

mod crc;
mod parser;

/// connect to serial
#[derive(Parser, Debug)]
#[command(version, about, long_about = None)]
struct ServerArgs {
    /// serial device name
    #[arg(short, long)]
    dev: Option<String>,
    /// dump column data and calculate score
    #[arg(long)]
    dump: bool,
}

/// Send packet to serial with specific type
#[derive(Parser, Debug)]
#[command(version, about, long_about = None)]
struct ClientArgs {
    /// Send packet type
    #[arg(long)]
    send_game_data: bool,
    #[arg(long)]
    pkt_type: Option<u8>,
    #[arg(long)]
    col: Option<u8>,
    #[arg(long)]
    data_int: Option<u64>,
}

fn main() {
    match TcpListener::bind("127.0.0.1:7878") {
        Ok(listener) => {
            println!("server mode");
            server(listener);
        }
        Err(e) => match e.kind() {
            io::ErrorKind::AddrInUse => {
                println!("client mode");
                client();
            }
            _ => {
                panic!("{:?}", e);
            }
        },
    }
}

fn server(listener: TcpListener) {
    let args = ServerArgs::parse();
    let mut dump = args.dump;

    // baud rate 28800
    let ports = serialport::available_ports().expect("No ports found!");
    for p in &ports {
        println!("{}", p.port_name);
    }
    let devname = match args.dev {
        Some(dev) => dev,
        None => ports[0].port_name.clone(),
    };
    let mut port = serialport::new(devname, 28800)
        .timeout(Duration::from_millis(10))
        .open()
        .expect("Failed to open port");
    let mut p2 = port.try_clone().unwrap();

    // forward socket to serial thread
    thread::spawn(move || {
        for stream in listener.incoming() {
            let mut stream = stream.unwrap();
            let mut buf = [0; 1024];
            let len = stream.read(&mut buf).unwrap();
            let buf = buf[..len].to_vec();
            p2.write_all(&buf).unwrap();
            println!("serial_send(hex): `{:02X?}`", buf);
        }
    });

    let mut packet_parser = PacketParser::new();

    // receive loop
    let mut cells: Vec<Vec<u8>> = vec![];
    loop {
        let mut serial_buf: Vec<u8> = vec![0; 1024];
        match port.read(serial_buf.as_mut_slice()) {
            Ok(t) => {
                println!("serial_recv(hex): {:02X?}", &serial_buf[..t]);
                packet_parser.extend(&serial_buf[..t]);
                let pkts = packet_parser.parse();
                if !pkts.is_empty() && dump {
                    port.write_all(&make_pkt(5, &[])).unwrap();
                    dump = false;
                }
                let pkts = pkts
                    .into_iter()
                    .filter(|p| p.typ != PING_TYPE)
                    .collect::<Vec<_>>();
                for pkt in pkts {
                    match pkt.typ {
                        3 => {
                            println!("type={} data={:02X?}", pkt.typ, pkt.data);
                            cells.push(pkt.data);
                        }
                        _ => {
                            println!("{:?}", pkt);
                        }
                    }
                }
                io::stdout().flush().unwrap();
                match cells.len().cmp(&130) {
                    Ordering::Equal => {
                        break;
                    }
                    Ordering::Greater => {
                        panic!("received too many cells");
                    }
                    Ordering::Less => (),
                }
            }
            Err(ref e) if e.kind() == io::ErrorKind::TimedOut => (),
            Err(e) => eprintln!("{:?}", e),
        }
    }
    let mut dino = 0_u32;
    let mut tetris = 0_u32;
    let mut snake = 0_u32;
    cells
        .iter()
        .filter(|cell| cell[0] >= 16)
        .for_each(|cell| match cell[0] {
            125 => {
                dino = u32::from_le_bytes(cell[1..5].try_into().unwrap());
            }
            126 => {
                tetris = u32::from_le_bytes(cell[1..5].try_into().unwrap());
                snake = u32::from_le_bytes(cell[5..9].try_into().unwrap());
            }
            _ => (),
        });
    let score: u32 = cells
        .into_par_iter()
        .filter(|cell| cell[0] < 16)
        .map(|cell| {
            let data = b"HITCON\0".iter().copied().chain(cell);
            let data = data.collect::<Vec<_>>();
            let hash = Sha3_256::digest(&data);
            let mut count = 0;
            for byte in hash {
                match byte.leading_zeros() {
                    8 => {
                        count += 8;
                    }
                    x => {
                        count += x;
                        break;
                    }
                }
            }
            count * count
        })
        .sum();
    let score = score / 16 + 1;
    println!("dino {}", dino);
    println!("tetris {}", tetris);
    println!("snake {}", snake);
    println!("score {}", score);
}

fn client() {
    let args = ClientArgs::parse();
    let mut stream =
        TcpStream::connect("127.0.0.1:7878").expect("Couldn't connect to the server...");

    if args.send_game_data {
        let col = args.col.unwrap();
        // python's equalivalent code: `data = bytes([args.col, *args.data_int.to_bytes(8, 'big')])`
        let mut data: Vec<u8> = vec![];
        data.push(col);
        data.extend(args.data_int.unwrap().to_be_bytes().iter());
        let pkt = make_pkt(3, &data);
        println!("send `{:02X?}`", pkt);
        stream.write_all(&pkt).unwrap();
    } else {
        let type_ = args.pkt_type.unwrap();
        let pkt = make_pkt(type_, &[]);
        println!("send `{:02X?}`", pkt);
        stream.write_all(&pkt).unwrap();
    }
}

fn make_pkt(type_: u8, data: &[u8]) -> Vec<u8> {
    let mut pkt: Vec<_> = b"\x55\x55\x55\x55\x55\x55\x55\xd5".to_vec();
    pkt.extend(b"\0\0"); // id
    pkt.extend([data.len() as u8]); // len
    pkt.extend([type_]); // type
    pkt.extend(b"\0\0\0\0"); // placeholder of checksum

    // copy a pkt and calculate checksum
    let mut pkt2 = pkt.clone();
    pkt2.extend(data);
    match pkt2.len() % 4 {
        1 => {
            pkt2.extend([0, 0, 0]);
        }
        2 => {
            pkt2.extend([0, 0]);
        }
        3 => {
            pkt2.extend([0]);
        }
        _ => (),
    }
    let checksum = Crc::default().hash_bytes(&pkt2);
    // finalize pkt
    pkt.drain(pkt.len() - 4..);
    pkt.extend(checksum);
    pkt.extend(data);
    pkt
}

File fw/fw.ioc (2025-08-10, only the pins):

Mcu.UserName=STM32F103CBTx
PA0-WKUP.GPIO_Label=IrRx
PA0-WKUP.Signal=GPIO_Input
PA1.Signal=ADCx_IN1
PA10.GPIO_Label=BtnH
PA10.Signal=GPIO_Input
PA11.GPIO_Label=UsbDm
PA11.Signal=USB_DM
PA12.GPIO_Label=UsbDp
PA12.Signal=USB_DP
PA13.Signal=SYS_JTMS-SWDIO
PA14.Signal=SYS_JTCK-SWCLK
PA15.GPIO_Label=BtnA
PA15.Signal=GPIO_Input
PA2.Signal=USART2_TX
PA3.Signal=USART2_RX
PA4.GPIO_Label=BtnB
PA4.Signal=GPIO_Input
PA5.GPIO_Label=BtnC
PA5.Signal=GPIO_Input
PA6.GPIO_Label=BtnD
PA6.Signal=GPIO_Input
PA7.GPIO_Label=BtnE
PA7.Signal=GPIO_Input
PA8.GPIO_Label=BtnF
PA8.Signal=GPIO_Input
PA9.GPIO_Label=BtnG
PA9.Signal=GPIO_Input
PB0.GPIO_Label=IrTx
PB0.Signal=S_TIM3_CH3
PB1.GPIO_Label=LedCh
PB1.Signal=GPIO_Output
PB10.GPIO_Label=LedCf
PB10.Signal=GPIO_Output
PB11.GPIO_Label=LedCe
PB11.Signal=GPIO_Output
PB12.GPIO_Label=LedCd
PB12.Signal=GPIO_Output
PB13.GPIO_Label=LedCc
PB13.Signal=GPIO_Output
PB14.GPIO_Label=LedCb
PB14.Signal=GPIO_Output
PB15.GPIO_Label=LedCa
PB15.Signal=GPIO_Output
PB2.GPIO_Label=LedCg
PB2.Signal=GPIO_Output
PB3.GPIO_Label=LedA0
PB3.Signal=GPIO_Output
PB4.GPIO_Label=LedA1
PB4.Signal=GPIO_Output
PB5.GPIO_Label=DEC_EN
PB5.Signal=GPIO_Output
PB6.Signal=I2C1_SCL
PB7.Signal=I2C1_SDA
PB8.GPIO_Label=LedA2
PB8.Signal=GPIO_Output
PB9.GPIO_Label=LedA3
PB9.Signal=GPIO_Output
PC14-OSC32_IN.GPIO_Label=USB_DET
PC14-OSC32_IN.Signal=GPXTI14
PC15-OSC32_OUT.GPIO_Label=IMU_PWR
PC15-OSC32_OUT.Signal=GPIO_Output
PD0-OSC_IN.Signal=RCC_OSC_IN
PD1-OSC_OUT.Signal=RCC_OSC_OUT

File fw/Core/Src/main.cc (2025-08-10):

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
/* Includes ------------------------------------------------------------------*/
#include "main.h"
#include "adc.h"
#include "crc.h"
#include "dma.h"
#include "tim.h"
#include "usart.h"
#include "usb_device.h"
#include "gpio.h"

/* USER CODE BEGIN Includes */
#include <Hitcon.h>
#include "i2c.h"

/* USER CODE END Includes */


void SystemClock_Config(void);
/**
  * @brief  The application entry point.
  * @retval int
  */
int main(void)
{

  /* MCU Configuration--------------------------------------------------------*/

  /* Reset of all peripherals, Initializes the Flash interface and the Systick. */
  HAL_Init();

  /* Configure the system clock */
  SystemClock_Config();

  /* Initialize all configured peripherals */
  MX_GPIO_Init();
  MX_DMA_Init();
  MX_USART2_UART_Init();
  MX_TIM1_Init();
  MX_TIM3_Init();
  MX_TIM2_Init();
  MX_TIM4_Init();
  MX_ADC1_Init();
  MX_CRC_Init();
  MX_USB_DEVICE_Init();
  /* USER CODE BEGIN 2 */
#ifndef V1_1
  MX_I2C1_Init();
#endif

#ifndef V2_2
  // configure PC15 as input to avoid conflicting with IMU_INT1
  GPIO_InitTypeDef GPIO_InitStruct = {0};
  GPIO_InitStruct.Pin = GPIO_PIN_15;
  GPIO_InitStruct.Mode = GPIO_MODE_INPUT;
  GPIO_InitStruct.Pull = GPIO_NOPULL;
  HAL_GPIO_Init(GPIOC, &GPIO_InitStruct);
#endif

  hitcon_run();

  /* USER CODE END 2 */

  /* Infinite loop */
  /* USER CODE BEGIN WHILE */
  while (1) {
    /* USER CODE END WHILE */

    /* USER CODE BEGIN 3 */
  }
  /* USER CODE END 3 */
}

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


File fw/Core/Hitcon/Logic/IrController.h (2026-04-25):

#ifndef LOGIC_IRCONTROLLER_DOT_H_
#define LOGIC_IRCONTROLLER_DOT_H_

#include <Logic/BadgeId.h>
#include <Logic/EcLogic.h>
#include <Logic/IrLogic.h>
#include <Service/EcParams.h>
#include <Service/IrService.h>
#include <Service/Sched/PeriodicTask.h>
#include <Service/Sched/Scheduler.h>
#include <stddef.h>
#include <stdint.h>

enum class packet_type : uint8_t {
  kGame = 0,  // disabled, 2024 Game
  kShow = 1,
  kTest = 2,
  // Packet types for 2025
  kAcknowledge = 3,
  kProximity = 4,            // disabled
  kPubAnnounce = 5,          // disabled
  kTwoBadgeActivity = 6,     // disabled
  kScoreAnnounce = 7,        // disabled
  kSingleBadgeActivity = 8,  // disabled
  kSponsorActivity = 9,      // disabled
  kShowMsg = 10,
  kRequestScore = 11,  // disabled
  kSavePet = 12,       // disabled
  kRestorePet = 13,    // disabled
};

// smaller value means higher priority
// only packets from badge need to have priority.
constexpr uint8_t RETX_LOWEST_PKT_PRIORITY = 0xF0;
constexpr uint8_t RETX_EMPTY_PKT_PRIORITY = 0xF1;
// for kRequestScore and kSavePet, not used now
constexpr uint8_t RETX_REPLACEMENT_PKT_PRIORITY = 0xF2;
constexpr uint8_t packet_priority[14] = {
    RETX_LOWEST_PKT_PRIORITY,  // kGame
    RETX_LOWEST_PKT_PRIORITY,  // kShow
    RETX_LOWEST_PKT_PRIORITY,  // kTest
    RETX_LOWEST_PKT_PRIORITY,  // kAcknowledge
    10,                        // kProximity
    0,                         // kPubAnnounce
    2,                         // kTwoBadgeActivity
    RETX_LOWEST_PKT_PRIORITY,  // kScoreAnnounce
    3,                         // kSingleBadgeActivity
    1,                         // kSponsorActivity
    RETX_LOWEST_PKT_PRIORITY,  // kShowMsg
    4,                         // kRequestScore
    5,                         // kSavePet
    RETX_LOWEST_PKT_PRIORITY   // kRestorePet
};
constexpr uint8_t GetPriority(packet_type type) {
  if (type < packet_type::kGame || type > packet_type::kRestorePet)
    return RETX_LOWEST_PKT_PRIORITY;
  return packet_priority[static_cast<uint8_t>(type)];
}
namespace hitcon {

namespace ir {

/*Definition of IR content.*/

struct ShowPacket {
  char message[16];
};

constexpr size_t PACKET_HASH_LEN = 6;

// This packet acknowledges a particular packet has been received.
struct AcknowledgePacket {
  // Hash of the packet being acknowledge.
  uint8_t packet_hash[PACKET_HASH_LEN];
};

// This packet is from base station to badge.
struct ShowMsgPacket {
  uint8_t user[BADGE_ID_LEN];
  char msg[24];
};

/*Definition of IR content.*/
constexpr size_t IR_DATA_HEADER_SIZE = 2;
struct IrData {
  uint8_t ttl;
  packet_type type;
  // WARNING: Be extra careful about alignment of all struct below, they MUST be
  // made of uint8_t to avoid padding introduced by compiler.
  union {
    struct ShowPacket show;
    struct AcknowledgePacket acknowledge;
    struct ShowMsgPacket show_msg;
  } opaq;
};
static_assert(sizeof(IrData) < 32);

constexpr size_t RETX_QUEUE_SIZE = 4;

constexpr uint8_t kRetransmitLimitMask = 0x07;
constexpr uint8_t kRetransmitStatusMask = 0xe0;
constexpr uint8_t kRetransmitStatusSlotUnused = 0x00;
constexpr uint8_t kRetransmitStatusWaitHashAvail = 0x20;
constexpr uint8_t kRetransmitStatusWaitHashDone = 0x40;
constexpr uint8_t kRetransmitStatusWaitTxSlot = 0x80;
constexpr uint8_t kRetransmitStatusWaitAck = 0xA0;

enum class AckTag : uint8_t {
  ACK_TAG_NONE = 0,
};

struct RetransmittableIrPacket {
  uint8_t status;
  // 0x07 - retransmit limit left.
  // 0xe0 - Status
  //   - 0x00 Slot is unused.
  //   - 0x20 Waiting for hashing processor to be available.
  //   - 0x40 Waiting for hashing processor to finish.
  //   - 0x80 Waiting for IrController's tx slot to open up.
  //   - 0xA0 Waiting for Ack.
  AckTag ack_tag;
  // Ack tag is used internally to denote special events.
  uint16_t time_to_retry;
  // In units of IR Retry task calls.
  uint8_t size;
  uint8_t data[MAX_PACKET_PAYLOAD_BYTES + 4];
  uint8_t hash[PACKET_HASH_LEN];
};

class IrController {
 public:
  IrController();

  void Init();
  void ShowText(char* text);
  void InitBroadcastService(uint8_t game_types);

  void SetDisableBroadcast() { disable_broadcast = true; }

  // Send a packet with data and size len.
  // An acknowledgement is expected (from base station) and will retry if no
  // acknowledgement is received.
  // Return true if the packet is accepted by IrController.
  // Return false if IrController is busy and cannot accept the packet.
  bool SendPacketWithRetransmit(uint8_t* data, size_t len, uint8_t retries,
                                AckTag ack_tag);

  // Query methods for debug interface
  uint8_t GetSlotStatusForDebug(uint8_t slot_index) const;
  uint8_t GetSlotPacketTypeForDebug(uint8_t slot_index) const;
  uint8_t GetSlotRetryCountForDebug(uint8_t slot_index) const;
  uint16_t GetSlotTimeToRetryForDebug(uint8_t slot_index) const;

  void ForceRetransmitForDebug(uint8_t slot_index);

 private:
  bool send_lock = true;
  bool recv_lock = true;
  // TODO: Tune the quadratic function parameters
  uint8_t v[3] = {1, 27, 111};
  bool disable_broadcast = false;

  // Number of packets received, primarily for debugging.
  size_t received_packet_cnt = 0;

  hitcon::service::sched::PeriodicTask routine_task;
  hitcon::service::sched::Task broadcast_task;

  IrData priority_data_;
  size_t priority_data_len_ = 0;

  RetransmittableIrPacket queued_packets_[RETX_QUEUE_SIZE];
  int current_hashing_slot = -1;
  int current_tx_slot = -1;

  // Called every 1s.
  void RoutineTask(void* unused);

  // Called on every packet.
  void OnPacketReceived(void* arg);

  int prob_f(int);

  void BroadcastIr(void* unused);
  void SendShowPacket(char* msg);

  bool TrySendPriority();

  // Periodic check on queued_packets_
  void MaintainQueued();

  // Called when we received an acknowledgment packet.
  void OnAcknowledgePacket(AcknowledgePacket* pckt);
  // Called by HashProcessor when hashing finished.
  void OnPacketHashResult(void* hash_result);

  // Called whenever we've some acknowledged packet.
  void OnAcknowledgeTag(AckTag tag);
};

extern IrController irController;

}  // namespace ir
}  // namespace hitcon

#endif  // #ifndef LOGIC_IRCONTROLLER_DOT_H_

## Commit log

2024-01-21 Create Project
    [pcb_badge.kicad_pcb, pcb_badge.kicad_sch]
2024-01-21 fix typo
    [pcb_badge.kicad_pcb, pcb_badge.kicad_sch]
2024-01-21 Split mcu and power sheets
    [MCU.kicad_sch, Power.kicad_sch, pcb_badge.kicad_sch]
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2024-01-21 Add LED Matrix
    [LED Matrix.kicad_sch, MCU.kicad_sch, pcb_badge.kicad_sch]
2024-01-28 Update Power sheet
    [MCU.kicad_sch, Power.kicad_sch, pcb_badge.kicad_sch]
2024-01-28 Revert "Update Power sheet"
    This reverts commit 4b511808635587c4bf1740382c23df6935c7ba79.
    [MCU.kicad_sch, Power.kicad_sch, pcb_badge.kicad_sch]
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2024-01-28 Update Power
    [Power.kicad_sch]
2024-01-28 Finish Schematic and add IRM-3638 to myLib
    [MCU.kicad_sch, pcb_badge.kicad_sch]
2024-01-30 Update some values and footprints
    [LED Matrix.kicad_sch, MCU.kicad_sch, Power.kicad_sch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]
2024-01-31 Update 74238 part name
    [LED Matrix.kicad_sch]
2024-03-02 Update: PCB LED Button Layout
    [MCU.kicad_sch, pcb_badge.kicad_pcb]
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2024-03-03 Change LED/R to 0402, changed OSC to SMD
    [LED Matrix.kicad_sch, MCU.kicad_sch, Power.kicad_sch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]
2024-03-03 Preliminary parts placement
    [LED Matrix.kicad_sch, MCU.kicad_sch, pcb_badge.kicad_pcb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]
2024-03-03 Did some layout
    [pcb_badge.kicad_pcb]
2024-03-07 Layout for dot matrix
    [MCU.kicad_sch, pcb_badge.kicad_pcb]
2024-03-09 Finish pcb routing
    [LED Matrix.kicad_sch, MCU.kicad_sch, Power.kicad_sch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]
2024-03-09 Move component text
    [pcb_badge.kicad_pcb]
2024-03-09 Fix wire
    [MCU.kicad_sch]
2024-03-09 Adjust wire width
    [pcb_badge.kicad_pcb]
2024-03-12 Add geber file
    [pcb_badge-B_Cu.gbr, pcb_badge-B_Mask.gbr, pcb_badge-B_Paste.gbr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]
2024-03-12 Update BOM
    [pcb_badge.csv]
2024-03-20 Add Cross Board Connector
    [MCU.kicad_sch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]
2024-03-24 WIP on board enlargement
    [MCU.kicad_sch, Power.kicad_sch, pcb_badge.kicad_pcb]
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2024-03-31 Fix led matrix symbol
2024-03-31 Add part number to LED Matrix symbol
    [LED Matrix.kicad_sch]
2024-03-31 Work in progress on larger PCB
    [pcb_badge.kicad_pcb]
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2024-03-31 Preliminary Layout for 13cm
    [MCU.kicad_sch, Power.kicad_sch, pcb_badge.kicad_pcb]
2024-03-31 Add zone for SMT microusb without support
    [Power.kicad_sch, pcb_badge.kicad_pcb]
2024-04-07 pinout for prototype 1
    [fw Debug.cfg]
2024-04-07 pinout for prototype 1
    (This version does not contain the changes to pcb files)
    [fw Debug.cfg]
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2024-04-13 Add second LED Matrix and change port layout
    [LED Matrix2.kicad_sch, MCU.kicad_sch, Power.kicad_sch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]
2024-04-13 Edit circuit and part designator
    [LED Matrix.kicad_sch, LED Matrix2.kicad_sch, MCU.kicad_sch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]
2024-04-14 Update schematic on protection circuitry
    [MCU.kicad_sch, Power.kicad_sch, pcb_badge.kicad_sch]
2024-04-14 Prepare board for layout
    [LED Matrix.kicad_sch, LED Matrix2.kicad_sch, pcb_badge.kicad_pcb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]
2024-04-17 WIP on 16x8 led matrix
    [pcb_badge.kicad_pcb]
2024-04-20 Draft layout for 8x16 dot matrix array
    [pcb_badge.kicad_pcb]
2024-04-20 WIP on MCU Layout
    [MCU.kicad_sch, pcb_badge.kicad_pcb]
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2024-04-21 Draft layout for proto3
    [MCU.kicad_sch, Power.kicad_sch, pcb_badge.kicad_pcb]
2024-04-21 Add extra large IR LED, fix LED parallel issue
    [MCU.kicad_sch, pcb_badge.kicad_pcb]
2024-04-28 Add LCSC part number to pcb project
    [BOM-pcb_badge.csv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]
2024-04-28 Correct FET footprint
2024-04-28 Update values and footprint
    Change 1n4001 to SOD4007
    footprint to SOD-123F
    Change R13 value to 0R
    modify Silkscreen
    [MCU.kicad_sch, Power.kicad_sch, pcb_badge.kicad_pcb]
2024-05-05 Update BOM and CPL
    R24 R25 change to 5.1k ohm
    [BOM-pcb_badge.csv, Power.kicad_sch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]
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2024-05-05 Update circuit and pcb layout
    Change R24 R25 circuit
    R19 from NC to 100k
    Silkscreen
    [LED Matrix.kicad_sch, MCU.kicad_sch, Power.kicad_sch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]
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2024-05-12 Minor fixes and removing debug parts/selections
    - Renamed EN to A3
    - Removed possibility of IR LED Direct Drive
    - Removed OSC Radd
    - Set NC to or-ing diode of boost out
    - Correct the osc part no
    - Set Rp of osc to 470R
    - NC OSC instead of GND
    [LED Matrix.kicad_sch, LED Matrix2.kicad_sch, MCU.kicad_sch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]
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2024-05-12 Move cross board connector back by 2.5mm
    [pcb_badge.kicad_pcb]
2024-05-12 Move IR LEDs around
    [pcb_badge.kicad_pcb]
2024-05-12 Adjust silkscreens to not overlap
    [pcb_badge.kicad_pcb]
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2024-05-12 Adjust part numbers and fix usb c NPTH hole/S1
    [LED Matrix2.kicad_sch, MCU.kicad_sch, Power.kicad_sch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]
2024-05-12 Clean out plotted output
    [pcb_badge-B_Cu.gbr, pcb_badge-B_Mask.gbr, pcb_badge-B_Paste.gbr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]
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2024-06-16 Add noise in pin
    [MCU.kicad_sch, pcb_badge.kicad_pcb]
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2024-06-16 Change git_rev text to back layer
    [pcb_badge.kicad_pcb]
2024-06-16 DisplayService test failed T_T
    [fw.ioc, main.cc, main.h]
2024-06-16 Add graphics and qrcode to silkscreen
    [pcb_badge.kicad_pcb]
2024-06-17 PCB refill zone and remove git rev on front
    [pcb_badge.kicad_pcb]
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2024-06-23 Adjust Graphics and fonts
    Adjust Graphics and fonts
    Update QRCode to pcb.hitcon.org/2024
    [pcb_badge.kicad_pcb]
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2024-06-23 Fix minor graphics error
    [pcb_badge.kicad_pcb]
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2024-06-23 Move Noise In to PA1
    [MCU.kicad_sch, pcb_badge.kicad_pcb]
2024-06-26 assign LCSC part number for 4.7Mohm resistor
    [pcb_badge.kicad_pcb]
2024-06-26 Move LDO to avoid the clip hole
    [pcb_badge.kicad_pcb]
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2024-06-26 Update various part number and jlcpcb mapping
    [MCU.kicad_sch, Power.kicad_sch, pcb_badge.kicad_pcb]
2024-06-26 Correct component rotation
    [BOM-pcb_badge.csv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]
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2024-06-26 Adjust silkscreen for J3
    [pcb_badge.kicad_pcb]
2024-06-27 Modify AAA battery case
    [Power.kicad_sch, pcb_badge.kicad_pcb]
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2024-06-27 Updated part mapping for 8.2M, 1206 110R and SW
    Also moved some via further away from battery holder.
    [MCU.kicad_sch, pcb_badge.kicad_pcb]
2024-06-27 Fixed mapping for STM32, IRM-H638 and the IR LED
2024-06-28 Fix rotation of switch
    [rotations.csv]
2024-06-28 Move C60 and R61 to back side
    [pcb_badge.kicad_pcb]
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2024-06-30 Fix some bug and add Init at main
    [main.cc]
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2024-07-07 Disable hitcon_run() to avoid issues
    [main.cc]
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2024-07-07 Fix compilation error on SetOnByteRx
    [XBoardService.cc]
2024-07-07 Fix incorrect detection of XBoard TX Queue full.
    [XBoardService.cc]
2024-07-08 fix lint and skip some parts of code
    [Hitcon.cpp, XBoardService.cc]
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2024-07-09 Fix display service dma interrupt
    [main.cc]
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2024-07-12 Fail to edit the DisplayService speed
    [main.cc]
2024-07-13 remove annoying env file since git filter with sed does not work on windows
2024-07-13 Revert "Fail to edit the DisplayService speed"
    This reverts commit 9150fc7f19b230647d253b8b70ab01756fe18625.
    [main.cc]
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2024-07-13 Update 2*AAA Battery Case footprint
    [pcb_badge.kicad_pcb]
2024-07-18 Change BT1 to NPTH
    [pcb_badge.kicad_pcb]
2024-07-20 Fix IR HW Test
    [Hitcon.cpp]
2024-07-21 fix: ir pin conflict between timer and uart
2024-07-21 Change project MCU F103C8 -> F103CB
    - Change project MCU F103C8 -> F103CB
    - Add Flash global interrupt
    [fw Debug.cfg]
2024-07-25 Add text on HITCON
    [pcb_badge.kicad_pcb]
2024-07-25 Remove the "HIT_" text
    [pcb_badge.kicad_pcb]
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2024-07-25 Fix IR LED Rotation
    [rotations.csv]
2024-07-27 Basic Functions (Some problems in Task)
    [IrController.h]
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2024-07-28 Fix hitcon init and add periodic test func
    [Hitcon.cpp]
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2024-08-10 fix showname app bug
    [Hitcon.cpp]
2024-08-10 Fix Dino game logic for obstacles
    [Hitcon.cpp]
2024-08-11 fix ircontroller due to packet change
    [IrController.h]
2024-08-17 Add hack-ish fix for XBoard error handling
    [XBoardService.cc]
2024-08-17 Drop baudrate to 28800 for stability
    [fw.ioc]
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2025-05-17 fix: assign PB5 as GPIO_Output
    due to TIM3_CH2 conflict with I2C1
    [fw.ioc, main.h]
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2025-08-10 fw: Auto resets Imu, and in case it doesn't work, show "ST"
    [ImuLogic.cc, ImuService.cc]
2025-08-10 skip imu self test, only test step count
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2025-08-10 fw: Adjust for faster reset
    [ImuLogic.cc, ImuService.cc]
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2025-08-13 fw: Adjust retx priority such that replacement will be taken before empty slot
    [IrController.h]
2025-08-13 [DO NOT MERGE] Demo on moddiv service running for too long
    [Hitcon.cpp]
2025-08-14 fix ButtonLogic
2026-04-25 fix(fw): dino app obstacle frame oob
2026-04-26 fix(fw): suppress warnings from switch case
    [ImuLogic.cc]
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2026-05-16 fix(fw): use button down to select next menu item
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

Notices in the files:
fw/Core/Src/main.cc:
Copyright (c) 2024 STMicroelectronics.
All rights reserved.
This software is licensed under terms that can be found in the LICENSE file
